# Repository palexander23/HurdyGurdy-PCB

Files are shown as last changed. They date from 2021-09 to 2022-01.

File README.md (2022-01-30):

# Electronic Hurdy Gurdy PCB

This repository contains PCB design files, that will go towards the eventual creation of an electronic Hurdy Gurdy.

This is a stand-in README that will likely be rewritten once the project starts taking off.

I do not intend this project to be seen widely, it's just a place for me to keep stuff.

This project was heavily inspired by the [Digi-Gurdy](https://hackaday.io/project/165251-the-digi-gurdy-and-diginerdygurdy) and much of the mechanical design for my instrument will likely be drawn from there.

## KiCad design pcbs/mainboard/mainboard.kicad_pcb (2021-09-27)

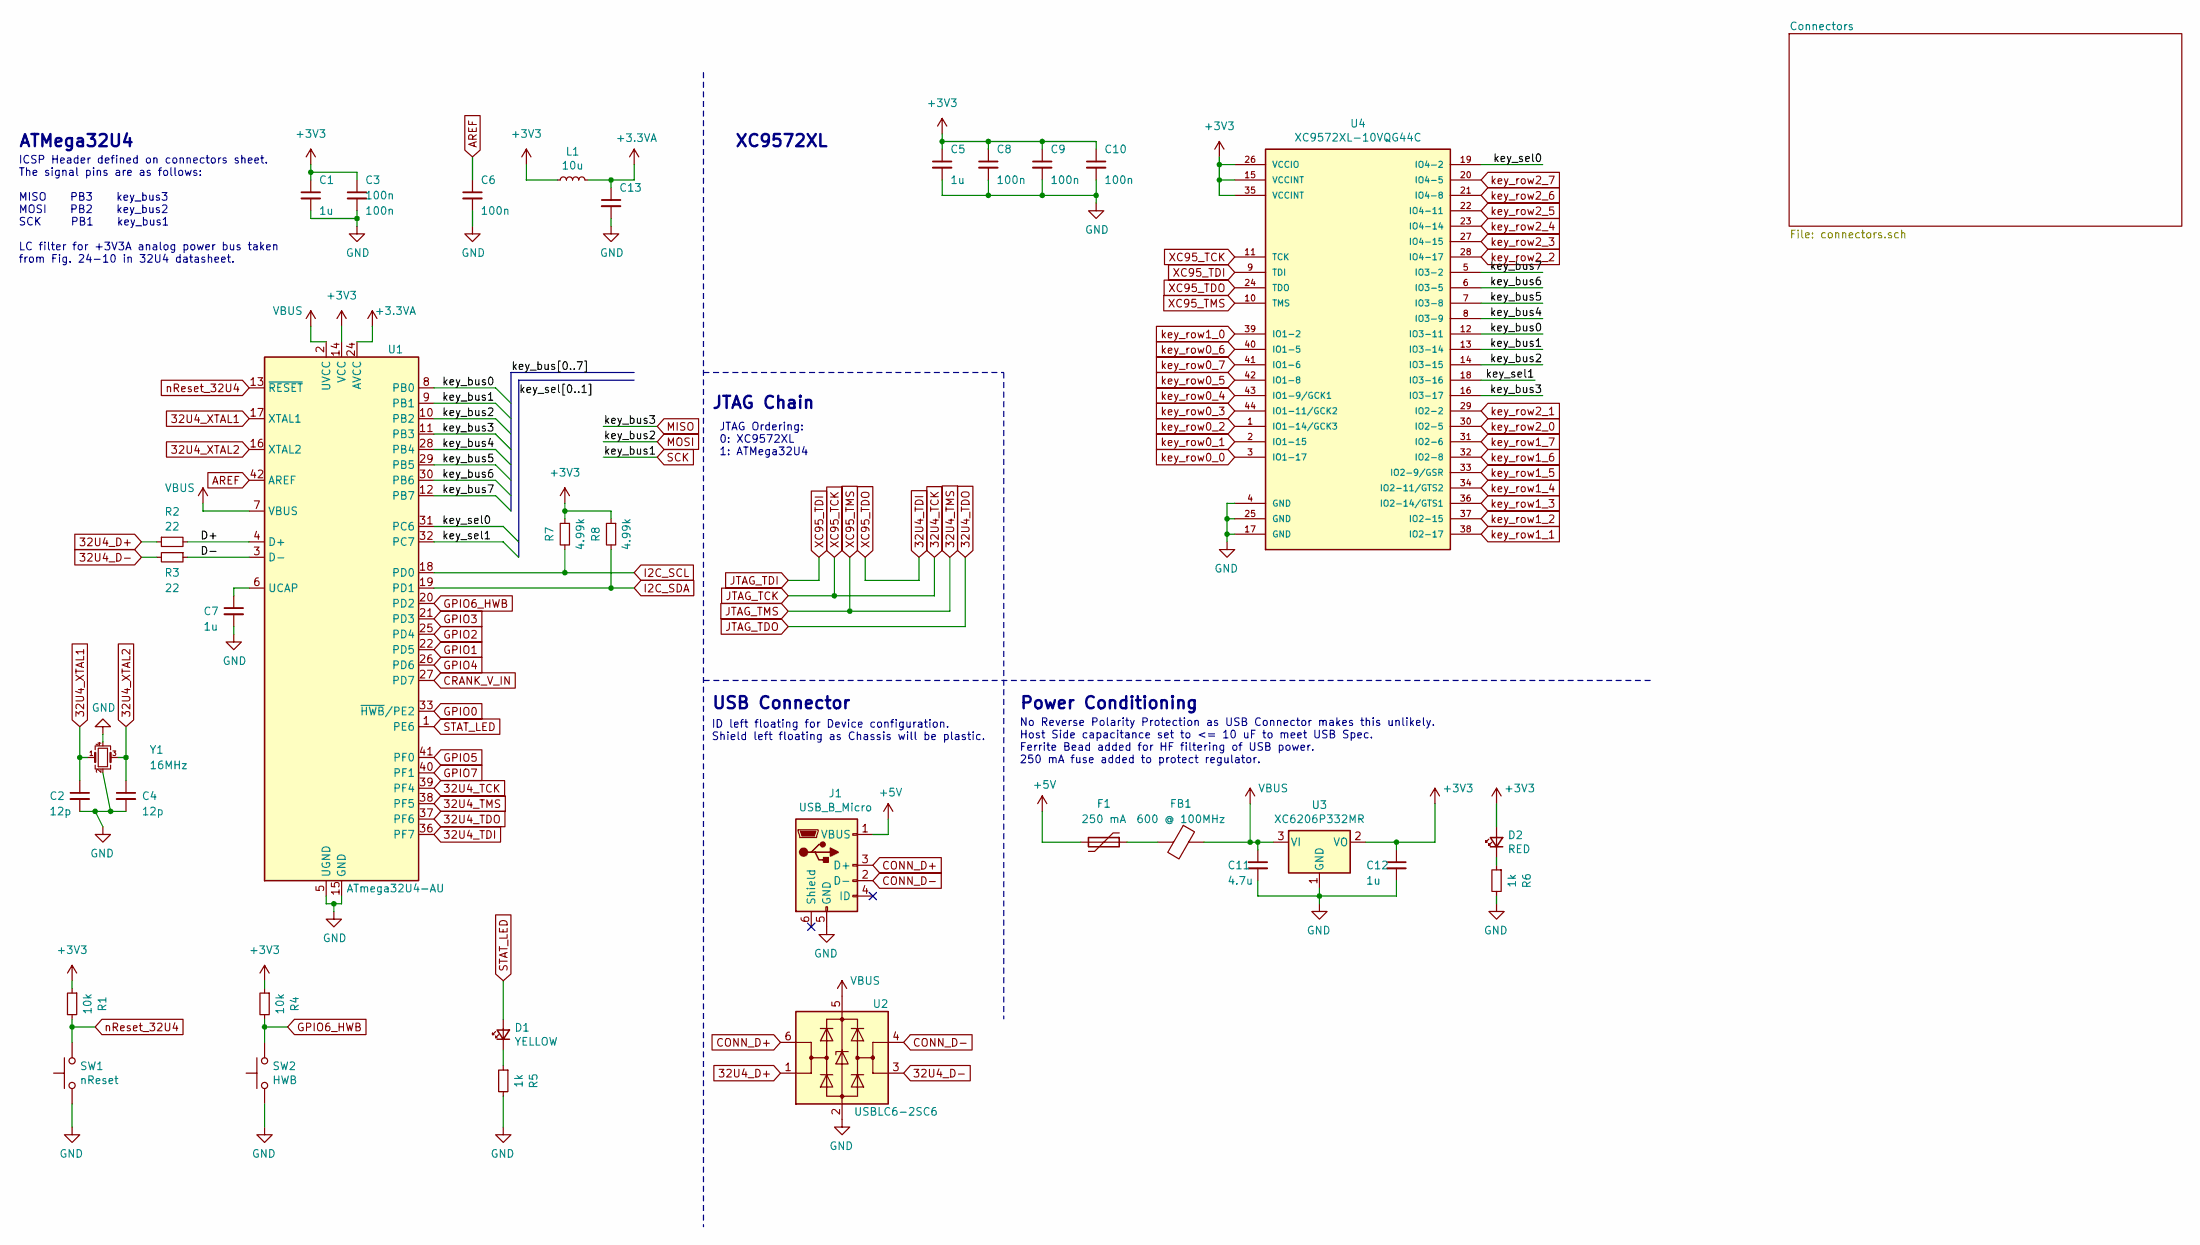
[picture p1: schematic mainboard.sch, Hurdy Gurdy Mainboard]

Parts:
C1, C5, C7, C12: 1u; C_0603_1608Metric; JLCPCB Part # C15849
C2, C4: 12p; C_0603_1608Metric; JLCPCB Part # C38523
C3, C6, C8, C9, C10, C13: 100n; C_0603_1608Metric; JLCPCB Part # C14663
C11: 4.7u; C_0603_1608Metric; JLCPCB Part # C19666
D1: YELLOW; LED_0603_1608Metric; JLCPCB Part # C72038
D2: RED; LED_0603_1608Metric; JLCPCB Part # C2286
F1: 250 mA; Fuse_1206_3216Metric; JLCPCB Part # C369154
FB1: 600 @ 100MHz; L_0805_2012Metric; JLCPCB Part # C1017
J1: USB_B_Micro; USB_Micro-B_Amphenol_10103594-0001LF_Horizontal
L1: 10u; L_1206_3216Metric; JLCPCB Part # C1051
R1, R4: 10k; R_0603_1608Metric; JLCPCB Part # C25804
R2, R3: 22; R_0603_1608Metric; JLCPCB Part # C23345
R5, R6: 1k; R_0603_1608Metric; JLCPCB Part # C21190
R7, R8: 4.99k; R_0603_1608Metric; JLCPCB Part # C23046
SW1: nReset; SW_PUSH_6mm
SW2: HWB; SW_PUSH_6mm
U1: ATmega32U4-AU; TQFP-44_10x10mm_P0.8mm; JLCPCB Part # C44854
U2: USBLC6-2SC6; SOT-23-6; JLCPCB Part # C2827654
U3: XC6206P332MR; SOT-23; JLCPCB Part # C5446
U4: XC9572XL-10VQG44C; VQFP-44; JLCPCB Part # C569042
Y1: 16MHz; Crystal_SMD_3225-4Pin_3.2x2.5mm; JLCPCB Part # C13738

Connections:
32U4_D+: R2.1, U2.1 (I/O1)
32U4_D-: R3.2, U2.3 (I/O2)
32U4_TCK: U1.39 (PF4), U4.11 (TCK); also elsewhere on the board
32U4_TDI: U1.36 (PF7), U4.24 (TDO)
32U4_TDO: U1.37 (PF6); also elsewhere on the board
32U4_TMS: U1.38 (PF5), U4.10 (TMS); also elsewhere on the board
32U4_XTAL1: C2.1, U1.17 (XTAL1), Y1.1
32U4_XTAL2: C4.1, U1.16 (XTAL2), Y1.3
+3.3VA: C13.1, L1.2, U1.24 (AVCC), U1.44 (AVCC)
+3V3: C1.1, C3.1, C5.1, C8.1, C9.1, C10.1, C12.1, D2.2 (A), L1.1, R1.1, R4.1, R7.1, R8.1, U1.14 (VCC), U1.34 (VCC), U3.2 (VO), U4.15 (VCCINT), U4.26 (VCCIO), U4.35 (VCCINT); also elsewhere on the board
+5V: F1.2, J1.1 (VBUS)
/D+: R2.2, U1.4 (D+)
/D-: R3.1, U1.3 (D-)
/key_bus0: U1.8 (PB0), U4.12 (IO3-11)
/key_bus4: U1.28 (PB4), U4.8 (IO3-9)
/key_bus5: U1.29 (PB5), U4.7 (IO3-8)
/key_bus6: U1.30 (PB6), U4.6 (IO3-5)
/key_bus7: U1.12 (PB7), U4.5 (IO3-2)
/key_sel0: U1.31 (PC6), U4.19 (IO4-2)
/key_sel1: U1.32 (PC7), U4.18 (IO3-16)
AREF: C6.1, U1.42 (AREF)
CONN_D+: J1.3 (D+), U2.6 (I/O1)
CONN_D-: J1.2 (D-), U2.4 (I/O2)
CRANK_V_IN: U1.27 (PD7); also elsewhere on the board
GND: C1.2, C2.2, C3.2, C4.2, C5.2, C6.2, C7.2, C8.2, C9.2, C10.2, C11.2, C12.2, C13.2, J1.5 (GND), R5.2, R6.2, SW1.1, SW2.1, U1.5 (UGND), U1.15 (GND), U1.23 (GND), U1.35 (GND), U1.43 (GND), U2.2 (GND), U3.1 (GND), U4.4 (GND), U4.17 (GND), U4.25 (GND), Y1.2, Y1.4; also elsewhere on the board
GPIO0: U1.33 (~HWB~/PE2); also elsewhere on the board
GPIO1: U1.22 (PD5); also elsewhere on the board
GPIO2: U1.25 (PD4); also elsewhere on the board
GPIO3: U1.21 (PD3); also elsewhere on the board
GPIO4: U1.26 (PD6); also elsewhere on the board
GPIO5: U1.41 (PF0); also elsewhere on the board
GPIO6_HWB: R4.2, SW2.2, U1.20 (PD2); also elsewhere on the board
GPIO7: U1.40 (PF1); also elsewhere on the board
I2C_SCL: R7.2, U1.18 (PD0); also elsewhere on the board
I2C_SDA: R8.2, U1.19 (PD1); also elsewhere on the board
JTAG_TDI: U4.9 (TDI); also elsewhere on the board
MISO: U1.11 (PB3), U4.16 (IO3-17); also elsewhere on the board
MOSI: U1.10 (PB2), U4.14 (IO3-15); also elsewhere on the board
unnamed: C7.1, U1.6 (UCAP)
unnamed: D1.1 (K), R5.1
unnamed: D2.1 (K), R6.1
unnamed: F1.1, FB1.2
SCK: U1.9 (PB1), U4.13 (IO3-14); also elsewhere on the board
STAT_LED: D1.2 (A), U1.1 (PE6); also elsewhere on the board
VBUS: C11.1, FB1.1, U1.2 (UVCC), U1.7 (VBUS), U2.5 (VBUS), U3.3 (VI); also elsewhere on the board
key_row0_0: U4.3 (IO1-17); also elsewhere on the board
key_row0_1: U4.2 (IO1-15); also elsewhere on the board
key_row0_2: U4.1 (IO1-14/GCK3); also elsewhere on the board
key_row0_3: U4.44 (IO1-11/GCK2); also elsewhere on the board
key_row0_4: U4.43 (IO1-9/GCK1); also elsewhere on the board
key_row0_5: U4.42 (IO1-8); also elsewhere on the board
key_row0_6: U4.40 (IO1-5); also elsewhere on the board
key_row0_7: U4.41 (IO1-6); also elsewhere on the board
key_row1_0: U4.39 (IO1-2); also elsewhere on the board
key_row1_1: U4.38 (IO2-17); also elsewhere on the board
key_row1_2: U4.37 (IO2-15); also elsewhere on the board
key_row1_3: U4.36 (IO2-14/GTS1); also elsewhere on the board
key_row1_4: U4.34 (IO2-11/GTS2); also elsewhere on the board
key_row1_5: U4.33 (IO2-9/GSR); also elsewhere on the board
key_row1_6: U4.32 (IO2-8); also elsewhere on the board
key_row1_7: U4.31 (IO2-6); also elsewhere on the board
key_row2_0: U4.30 (IO2-5); also elsewhere on the board
key_row2_1: U4.29 (IO2-2); also elsewhere on the board
key_row2_2: U4.28 (IO4-17); also elsewhere on the board
key_row2_3: U4.27 (IO4-15); also elsewhere on the board
key_row2_4: U4.23 (IO4-14); also elsewhere on the board
key_row2_5: U4.22 (IO4-11); also elsewhere on the board
key_row2_6: U4.21 (IO4-8); also elsewhere on the board
key_row2_7: U4.20 (IO4-5); also elsewhere on the board
nReset_32U4: R1.2, SW1.2, U1.13 (~RESET); also elsewhere on the board

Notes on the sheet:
ATMega32U4
XC9572XL
JTAG Chain
JTAG Ordering: 0: XC9572XL 1: ATMega32U4
USB Connector
ID left floating for Device configuration. Shield left floating as Chassis will be plastic.
Power Conditioning
No Reverse Polarity Protection as USB Connector makes this unlikely. Host Side capacitance set to <= 10 uF to meet USB Spec. Ferrite Bead added for HF filtering of USB power. 250 mA fuse added to protect regulator.
ICSP Header defined on connectors sheet. The signal pins are as follows: MISO PB3 key_bus3 MOSI PB2 key_bus2 SCK PB1 key_bus1 LC filter for +3V3A analog power bus taken from Fig. 24-10 in 32U4 datasheet.

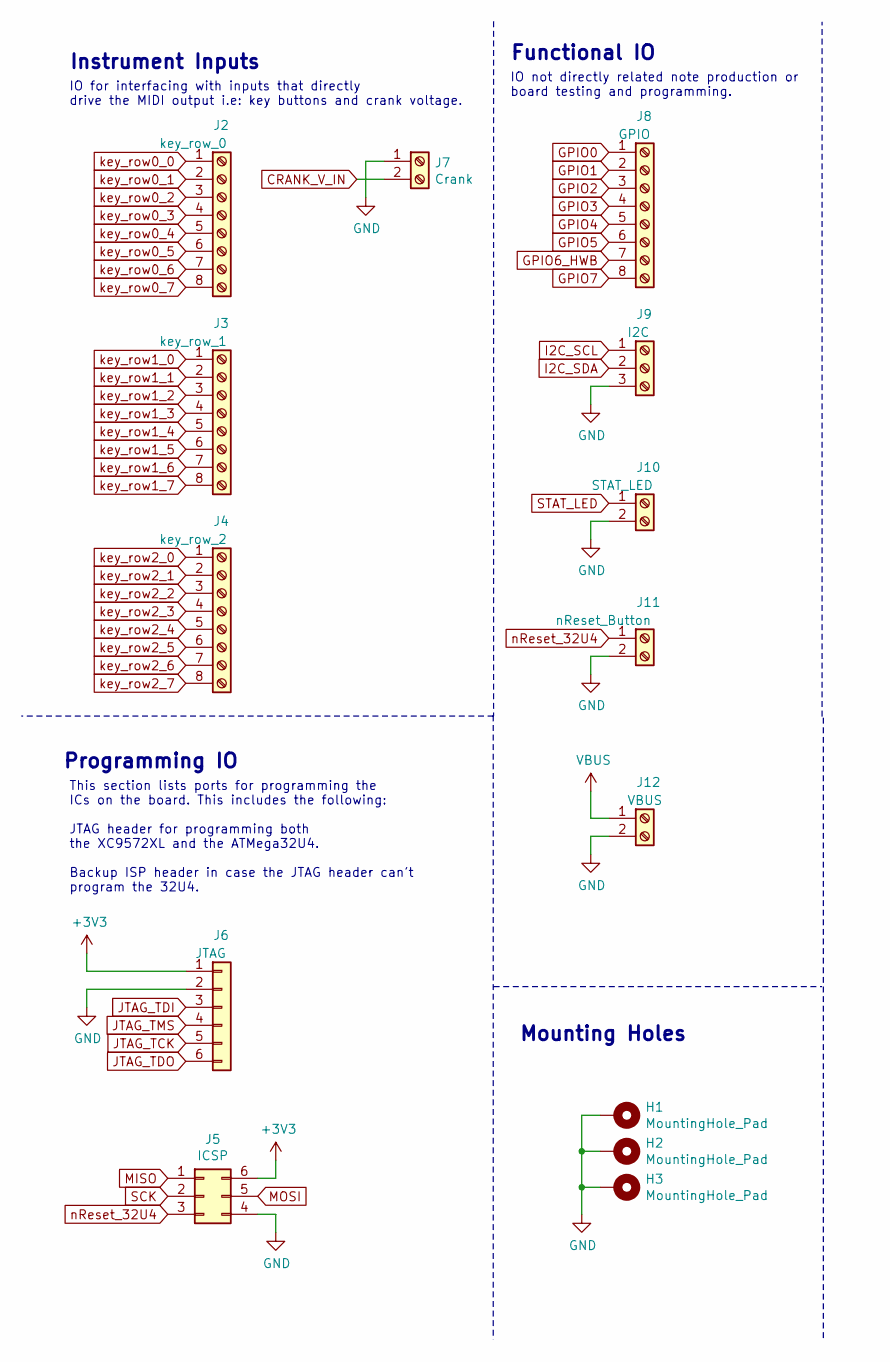
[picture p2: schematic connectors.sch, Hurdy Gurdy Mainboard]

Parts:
H1, H2, H3: MountingHole_Pad; MountingHole_3.2mm_M3_Pad_Via
J2: key_row_0; TerminalBlock_Phoenix_MKDS-1,5-8-5.08_1x08_P5.08mm_Horizont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
J3: key_row_1; TerminalBlock_Phoenix_MKDS-1,5-8-5.08_1x08_P5.08mm_Horizont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
J4: key_row_2; TerminalBlock_Phoenix_MKDS-1,5-8-5.08_1x08_P5.08mm_Horizont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
J5: ICSP; PinHeader_2x03_P2.54mm_Vertical
J6: JTAG; PinHeader_1x06_P2.54mm_Vertical
J7: Crank; TerminalBlock_Phoenix_MKDS-1,5-2-5.08_1x02_P5.08mm_Horizont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
J8: GPIO; TerminalBlock_Phoenix_MKDS-1,5-8-5.08_1x08_P5.08mm_Horizont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
J9: I2C; TerminalBlock_Phoenix_MKDS-1,5-3-5.08_1x03_P5.08mm_Horizont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
J10: STAT_LED; TerminalBlock_Phoenix_MKDS-1,5-2-5.08_1x02_P5.08mm_Horizont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
J11: nReset_Button; TerminalBlock_Phoenix_MKDS-1,5-2-5.08_1x02_P5.08mm_Horizont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
J12: VBUS; TerminalBlock_Phoenix_MKDS-1,5-2-5.08_1x02_P5.08mm_Horizont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

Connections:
32U4_TCK: J6.5; also elsewhere on the board
32U4_TDO: J6.6; also elsewhere on the board
32U4_TMS: J6.4; also elsewhere on the board
+3V3: J5.6, J6.1; also elsewhere on the board
CRANK_V_IN: J7.2; also elsewhere on the board
GND: H1.1, H2.1, H3.1, J5.4, J6.2, J7.1, J9.3, J10.2, J11.2, J12.2; also elsewhere on the board
GPIO0: J8.1; also elsewhere on the board
GPIO1: J8.2; also elsewhere on the board
GPIO2: J8.3; also elsewhere on the board
GPIO3: J8.4; also elsewhere on the board
GPIO4: J8.5; also elsewhere on the board
GPIO5: J8.6; also elsewhere on the board
GPIO6_HWB: J8.7; also elsewhere on the board
GPIO7: J8.8; also elsewhere on the board
I2C_SCL: J9.1; also elsewhere on the board
I2C_SDA: J9.2; also elsewhere on the board
JTAG_TDI: J6.3; also elsewhere on the board
MISO: J5.1; also elsewhere on the board
MOSI: J5.5; also elsewhere on the board
SCK: J5.2; also elsewhere on the board
STAT_LED: J10.1; also elsewhere on the board
VBUS: J12.1; also elsewhere on the board
key_row0_0: J2.1; also elsewhere on the board
key_row0_1: J2.2; also elsewhere on the board
key_row0_2: J2.3; also elsewhere on the board
key_row0_3: J2.4; also elsewhere on the board
key_row0_4: J2.5; also elsewhere on the board
key_row0_5: J2.6; also elsewhere on the board
key_row0_6: J2.7; also elsewhere on the board
key_row0_7: J2.8; also elsewhere on the board
key_row1_0: J3.1; also elsewhere on the board
key_row1_1: J3.2; also elsewhere on the board
key_row1_2: J3.3; also elsewhere on the board
key_row1_3: J3.4; also elsewhere on the board
key_row1_4: J3.5; also elsewhere on the board
key_row1_5: J3.6; also elsewhere on the board
key_row1_6: J3.7; also elsewhere on the board
key_row1_7: J3.8; also elsewhere on the board
key_row2_0: J4.1; also elsewhere on the board
key_row2_1: J4.2; also elsewhere on the board
key_row2_2: J4.3; also elsewhere on the board
key_row2_3: J4.4; also elsewhere on the board
key_row2_4: J4.5; also elsewhere on the board
key_row2_5: J4.6; also elsewhere on the board
key_row2_6: J4.7; also elsewhere on the board
key_row2_7: J4.8; also elsewhere on the board
nReset_32U4: J5.3, J11.1; also elsewhere on the board

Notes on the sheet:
Instrument Inputs
IO for interfacing with inputs that directly drive the MIDI output i.e: key buttons and crank voltage.
Functional IO
IO not directly related note production or board testing and programming.
Programming IO
This section lists ports for programming the ICs on the board. This includes the following: JTAG header for programming both the XC9572XL and the ATMega32U4. Backup ISP header in case the JTAG header can't program the 32U4.
Mounting Holes

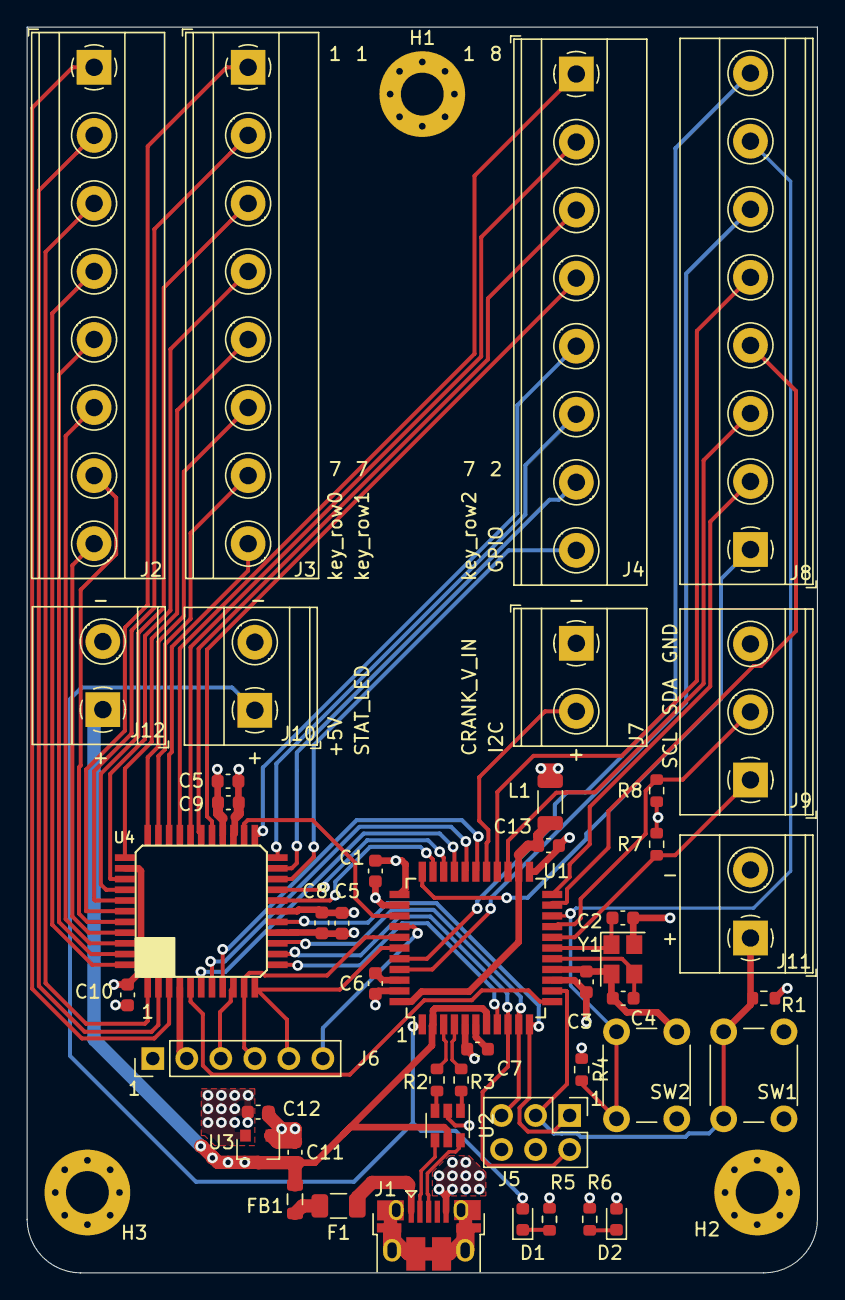
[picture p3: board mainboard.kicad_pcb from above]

Board: 4 copper layers, 59.0 x 93.0 mm, 49 parts (0 on the bottom side), 70 nets.

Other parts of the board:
C5#2: 100n; C_0603_1608Metric

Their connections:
+3V3: C5#2.1; also elsewhere on the board
GND: C5#2.2; also elsewhere on the board

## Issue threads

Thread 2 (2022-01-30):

Update MCU

palexander23, 2022-01-30:
- [ ] Replace MCU
- [ ] Redesign Key Interface
- [ ] Resize Board Dimensions

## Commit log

2021-09-13 Add WIP mainboard schemetic: Power, MCU, USB
    Add Schematic blocs for:
    * ATMega32U4 MCU
    * XC9572XL CPLD for key management
    * JTAG Chain
    * Power Regulation/Conditioning
    * USB Input/ESD Protection
    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
    [mainboard.kicad_pcb, mainboard.sch]
2021-09-17 Add completed schematic with footprints
    Add completed schematic with connectors for all IO and programming
    devices.
    Connectors laid out on a separate sheet.
    DRC check completed.
    One rule left unfulfilled resulting from KiCAD not recognising when
    a power signal has run all but undisturbed through a power filter.
    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
    [connectors.sch, mainboard.sch]
2021-09-22 Add 3V3A filter and JLC Part numbers
    Add a single stage LC filter to the ADC power input.
    Design taken from Fig. 24-10 in 32U4 datasheet.
    Add JLC part numbers for all SMD parts.
    XC95 part was out of stock at time of commit.
    [mainboard.sch]
2021-09-22 Add mounting holes and fix button footprint
    Replace button footprint with one which matches the symbol.
    [connectors.sch, mainboard.sch]
2021-09-22 Add VBUS screw terminal
    Add VBUS screw terminal to allow future subsystems to draw current
    from the USB connection, bypassing the small 3V3 regulator.
    [connectors.sch]
2021-09-22 Edit bypass capacitors, add JLC part for LDO
    Both 32U4 and XC95 now bave 1uF bulk capacitor as well as a 100nF
    for each VCC/GND pair.
    [mainboard.sch]
2021-09-24 Add first draft of mainboard layout
    Change pinout of XC95 to better link to the key_row screw terminals.
    Change ordering of some signals on screw terminals and JTAG header
    to allow more sensible routing.
    Revise mounting hole scheme to only place one between the two rows
    of terminal blocks rather than at each corner on the top.
    [connectors.sch, mainboard.kicad_pcb, mainboard.sch]
2021-09-24 Add first draft of mainboard routing
    [mainboard.kicad_pcb, mainboard.sch]
2021-09-26 Improve routing around 32U4
    Move some pin assignments round on the 32U4 to simplify routing
    to the lower-priority IO.
    [mainboard.kicad_pcb]
2021-09-26 Fix vias placed under SMD pads
    Move vias out from underneath SMD pads to prevent solder paste
    being sucked into them during manufacture.
    Redo power layout to accomadate large areas of vias to power planes.
    [mainboard.kicad_pcb]
2021-09-26 Add useful/readabhle silkscreen
    Swap pins on CRANK_V_IN terminal block to shorten track
    and match the polarity of other +/- terminal blocks.
    [connectors.sch, mainboard.kicad_pcb, mainboard.sch]
2021-09-27 Move H2, H3 up to ease USB port chassis placement
    Move mounting holes H2 and H3 up a few mm to allow the USB port to
    allow the USB port to be placed as close to the edge of the
    chassis as possible.
    [mainboard.kicad_pcb]
2021-09-27 Add copper pour keepout under crystal
    [mainboard.kicad_pcb]
2022-01-30 Update README to match repo rename
    Update README to match the repo rebranding for PCBs
